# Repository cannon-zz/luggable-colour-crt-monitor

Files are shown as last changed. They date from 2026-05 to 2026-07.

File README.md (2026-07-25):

# Colour CRT Monitor for a Retro Luggable Computer

I'm in the process of assembling a luggable Apple ][ clone system.  This is the colour monitor part of the project.

This monitor started out as a SKYTEK brand SCT-1024 portable colour television from May of 1988 that I picked up from an auction site.  The video baseband and CRT driver section is built around a Panasonic 150CHB22 picture tube driven by a Toshiba TA7698AP video-chroma-deflection system all-in-one chip.  I think those picture tubes were quite common in small televisions of this type, and the all-in-one chip is easy to find, so this project might be useful for others looking for a way to make a small DIY CRT colour monitor from salvaged parts.

## Status

- [X] First pass through the circuit, entering it into kicad.
  - CRT socket board not included.  Will reuse as-is.
  - 11 V regulator circuit not included.  Considering alternatives.
- [X] Remove components from PCB, confirm values out-of-circuit.
  - Confirm internal structure of flyback.
  - Identify coils, diodes, capacitors.
- [X] Select new replacement parts.
- [X] Assign footprints.
- [X] Layout PCB.
- [X] Parts and PCBs ordered.
- [ ] Assembled.
- [ ] Tested and working (knock on wood).

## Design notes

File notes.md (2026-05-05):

# Notes

There are no documents for this specific make and model online that I can find.  The data sheet for the TA7698AP chip is available, which includes a reference circuit for an NTSC application.  That chip was used in at least one colour television service technician training kit, so there's a lot of helpful tutorial-like material floating around online about the operation and maintenance of circuits based on it.  Researching small portable televisions I learned that SKYTEK was probably one of a pantheon of small Korean and Taiwanese companies that licensed or copied older Japanese designs and sold them into the discount market, and based on that I looked for cosmetically similar Japanese televisions and found the JVC CX-60, which appears to be physically identical.  Service manuals for the PAL/SECAM European version of the CX-60 are available online, but not NTSC.  Other than the colour processing circuits, the schematic matches almost exactly what's inside this television, even the component designators are identical or closely related, and so should provide a useful guide for adjusting the circuit.

Using the PAL/SECAM CX-60ME service manual and the TA7698AP data sheet as guides, I traced out the schematic for my set.  The two major differences from the CX-60ME are:
* The absence of the PAL/SECAM colour processing circuitry ... replaced with a tint control.
* The SKYTEK has a different fly-back transformer, with fewer taps on the primary winding.  In particular, the CX-60 derives a +17 V DC supply for the vertical deflection circuit from one of its transformer's primary's taps, whereas the SKYTEK doesn't have that and uses its main regulated 11 V DC supply to power the vertical deflection.  The substantially lower voltage leads to significantly different component values in that part of the circuit.

## Power Supply

The TV's DC barrel jack is labelled "12 V".  It was powered by an external unregulated DC power supply labelled an oddly precise 14.7 V at 1.3 A.  The TV was also intended to be powered from an automotive cigarette lighter, so it was basically getting fed about 14 V, unregulated.  Internally, that feeds a linear 11.0 V DC regulator from which everything is powered.  That regulator is precise:  it has a temperature compensated zener reference and a voltage adjust pot.  So the circuit needs a clean, precise, regulated 11.0 V supply.  It would be very convenient if the circuit could run on a (clean, regulated) 12 V supply because that's one of the power supplies the computer already has.

Most of the circuit is actually powered by a 10-ish V rail which is derived from the 11 V rail using a simple series drop resistor.  Adjusting that resistor is probably all that's needed to accommodate a higher 12 V supply.  The real problem is the horizontal and vertical deflection circuits.  I don't know enough about these circuits to understand how the supply voltage affects the component values needed to get the amplitude and frequency of the oscillations in spec.  However, given the dramatic changes in resistor values for the transistor biasing in the vertical deflection circuit compared to the CX-60, where that circuit runs on 17 V, I think changing the supply voltage to these circuits needs to be done with care.  For now I'm expecting to have to include an 11.0 V regulator circuit.

Oddly, the TA7698AP data sheet recommends a supply voltage of 12 V, and says the minimum operating voltage is 10.8 V, which is *above* the voltage indicated on the VCC pin in the CX-60 schematic (10.6 V).

## Diodes

All diodes specified to be 1SS133 in the CX60 schematic are, here, parts marked "48T" around their barrel, or some cyclic permutation thereof (don't know where the start and end of the sequence are).  I believe they are 1N4148 equivalent.

D303 that does something I don't understand for the vertical deflection coil's high-side drive transistor is a 1SR35-100A in the CX60 schematic, and I don't know what's installed in the SKYTEK.  The 1SR35-100A datasheet is easy to find, but the part isn't.  I'll use a 1N4935.

D404 is a TVR06D, and D408 is an RGP10G.  These can also both be replaced with 1N4935.  I'll order extra 1N4935s, but to start I'll reuse the parts for these I have.

The diode (D405) used to rectify the 90 V supply for the CRT socket board has burned the PCB.  That's the only place on the PCB with evidence of heat, the only indication of a component that needed to handle more power than it was rated for.  I don't know what the diode is, I can't make heads or tails of the markings on it ("K4K4"), but I want to choose something else.  The diode seems healthy, so my plan is to re-use it, then with it in circuit measure the current and voltage it needs to handle, and replace it with something beefier that doesn't get as hot.  The CX60 used an ISR124-400A which is a 400 V 1 A high-speed rectifier diode.

In the CX60 schematic the horizontal pulse signal providing a phase sense feedback from the horizontal fly-back circuit feeds into four portions of the circuit:
1. a circuit to derive a horizontal blanking signal that gets mixed into the luminance;
2. the circuit tuning the horizontal oscillator;
3. the TA7698AP's h pulse in / gate pulse out pin;
4. the PAL/SECAM colour processor chip.

In the CX60, the 3 and 4 circuits share the same initial portions, including a zener diode (D303) to clamp the positive-going pulse amplitude.  A very similar but completely independent circuit is used for 1, which also includes a zener diode (D502) but where that diode creates a DC bias voltage and is not used to clamp the pulse amplitude.  The TV I've got has a nearly identical circuit for 2, and does not have the PAL/SECAM colour processor, and it combines 1 and 3 into a single circuit.  That circuit has basically the same parts as used in 3 above, but instead of a zener diode to clamp the positive-going voltage there is simply another "48T" diode (D402), identical to all the rest on the board.  This is more like the reference circuit in the data sheet, which shows a normal diode in this position.  I don't know what to make of this.  Did the person screw up and put the wrong component into this position, should it have been a zener diode?  Is the reference circuit in error?

I've decided to assume the reference circuit is correct, the diode does not need to clamp the positive-going voltage, and it can be the same as the other small signal diodes in the circuit.

## Inductors

All of the normal inductors I've managed to measure and document, but there are two that I don't know what to make of.

There is a tunable inductor thingy connected to the TA7698AP'S "burst cleaning" pin.  The package is marked KRFE204, and the circuit diagrams suggest it's a capacitor and variable inductor in parallel inside a single box.  The package I have has 5 pins, not including the tabs on the shield surrounding it, and only 2 of the 5 are used, the rest are all grounded.  I don't know what its parameters are or what it is exactly.  I'm reusing the one I pulled out of the TV, and will reconnect it the way it was hooked up.  Looking at the chip's block diagram, the various schematics, and considering what the pin description says about it, I /believe/ you're supposed to connect a DC-isolated LC band-reject filter to pin 10 that is tuned to the colour sub-carrier frequency (~3.58 MHz for NTSC) and that shunts everything away from its centre frequency to ground.  The pin description says the LC tank circuit's alignment can be used to shift the phase of the chroma signal w.r.t. the colour burst phase reference.  So ... I think you should look for a 3.58 MHz tunable LC circuit in a can which is to be deliberately mistuned slightly to provide a phase shift and tweak the colours.  I am expecting to adjust it by putting the tint control in the centre, and tweaking the inductor until the colours look right.  There are instructions in the CX60ME manual for adjusting this component (which it calls a transformer), but I don't yet know if they work for this circuit because of the differences in NTSC chroma processing.

There is also a transformer used to drive the horizontal output transistor.  Televisions seem to always include such a transformer, I don't really understand why, and so I don't know what this thing's properties are supposed to be.  I'm reusing the one I pulled out of the TV and connecting it up the way I found it.  Measuring this transformer:
 - grounded pins 2 and 4 (signal generator and oscilloscope chassis);
 - placed 15 kHz sine wave into pin 1, measured it to be 1 V peak-to-peak using 1 MOhm oscilloscope probe in parallel across winding;
 - simultaneously observed 250 mV peak-to-peak sine wave in phase on pin 3 with a second 1 MOhm oscilloscope probe across the winding;
 - with the ground lead for the probe on the secondary disconnected the amplitude increased to 1 V peak-to-peak.
 - the primary is measured to be 11 mH at 10 kHz with the secondary open, and 0.93 mH with the secondary shorted.

For the two ferrite beads, L401 and L409, using a dual binding post to BNC adapter + BNC to SMA adapter, I used a NanoVNA to try to characterize these.  If the measurements I made are correct, below 30 MHz these have almost 0 Ohm impedance, above 30 MHz they begin to absorb, and have a peak absoption at about 160 MHz.

## Resistors

All blue resistors had drifted upwards, all were consistently measured 10% above their marked value.

### Variable resistors

All variable resistors measured consistently 20% below their marked value.  The fact that the deviation is systematic points to a manufacturing flaw, but normal non-precision variable resistors usually only have a 20% or even 30% tolerance, so these would probably all be within the manufacturer's specifications.  Nevertheless I'll replace them all.

Some are hard to source:
- 470 Ohm vertical centre.  with no load on wiper, wiper potential varies from 3.5 V to 9.1 V, or 32% to 83% of the deflection potential.  in the CX60 circuit, with different resistances and the vertical deflection running on 17 V, the unloaded wiper's potential varies from 6.3 V to 12.6 V, or 37% to 74% of the deflection potential.
- 200 kOhm vertical hold

Easy to obtain locally are Alps Alpine RK09K series potentiometers.  for the three 10 kOhm, non-detent, pots I got RK09L1140-F15-C0-B103:
- 15 mm from body to top of shaft
- 5 mm M9x0.75 threaded sleeve
- 6 mm flat D shaft
- 300 degree rotation
- pins comatible with 2.54 mm grid
- 10 mm from PCB to front-panel mating surface
- 50 mW
Mouser has the centre detent version RK09L114001E

TT Electronics P0915N-FCxxx are nearly mechanically compatible, but have an M7x0.75 threaded shaft.  there isn't a 200 kOhm variant.

settled on Bourns PDB12-F4201-204BF for the 200 kOhm vertical hold adjustment.  this is larger, physically, than the others, does not have a threaded bushing, but its PCB to front-panel mating surface height is nearly the same at 9 mm, however the total length is about 5 mm shorter from PCB surface to end of shaft.  hopefully the difference won't be noticed once knobs get pushed onto the shafts.

it would be much more convenient if the vertical hold adjustment R351 could be implemented with a 100 kOhm pot.  upping R306 to 270 kOhm and adding a 50 kOhm resistor in series after R351 would allow R351 to be reduced to 100 kOhm without changing the total series resistance, but it would cut the adjustment range in half.

## Transistors

### 2SC200

Can't find a manufacturer's datasheet for the 2SC200 transistor, Q401, the NPN used to drive the horizontal output transformer.  Web sites that claim to have data for this part contradict each other.  What I have found:
 - A contemporary transistor parameter table lists it as a Fujitsu part having RF conversion mixer, oscillator and power amplifier applications, states the collector-base breakdown voltage is 40 V, the max collector current is 300 mA, the max dissipated power is 600 mW, max junction temperature is 175 C, the transition frequency is 350 MHz, and the current gain is 60.
 - A contemporary cross-reference table says the 2SC200 can be replaced with:  2SC1175, 2SC594, 2SC138, 2SC139, 2SC696, 2SC741
 - The CX60 uses a 2SD639-Q or -R for its Q501, the equivalent in its circuit.  Those have:  collector-base breakdown voltage of 60 V, collector-emitter breakdown voltage of 50 V, max collector current 500 mA, max dissipated power 600 mW, max temperature 150 C, transition frequency of 200 MHz, and a current gain between 85 and 240.
 - One non-contemporary web site claims the transistor has a collector emitter breakdown voltage of 45 V, a max collector current of 0.5 A, dissipates a maximum of 0.625 W, has a transition frequency of 300 MHz, and that the Y rating will have a current gain between 120 and 240.
 - That site claims it can be replaced with:  2SC2274, 2SC2274K, 2SC2277, 2SC2655, 2SC3243, 2SC3328, 2SC3916, 2SC3917, 2SC3918, 2SC3919, 2SC3920, 2SC3921, 2SC3922, 2SC3923, 2SD438, 2SD667, 2SD863, BC635, KSC1008C, KSC2331, KTC200, KTC3209 or KTD863.
 - Another non-contemporary web site claims it has a collector base breakdown voltage of 40 V, a max collector current of 0.3 A, dissipates a maximum of 0.65 W, has a transition frequency of 175 MHz, and a current gain of 60 (regardless of rating).
 - 2N5551, 2SCR514R might be suitable modern replacements, or maybe just a 2N2222

## Delay Line

I have no idea what this is.  "Sangshin DL601T" is written on it, but I can't find any information on that.  The CX60 schematic isn't helpful because that's for a PAL/SECAM television which would need a different component here.  The TDA7698AP reference circuit shows a TRF2033 or TRP2033 (bad scan) used in this part of the circuit, and I can't find any information about that on the internet.  The schematic calls it a 3.58 MHz trap, and the block diagram suggests it is an LC band reject filter combined with a delay line.

I tried injecting a 100 mV sine wave into pin 1, grounding pin 2, looking at the output on pin 3, and sweeping the frequency between 1 MHz and 5 MHz.  It definitely seems to be a filter, but my quickie hack wasn't enough to get a sense of what kind it is.  However, if it's also a delay line that's hard to tell.  At low frequencies, below 100 kHz, there's no obvious phase difference, no time delay between the input and output signals.  Increasing the frequency reveals a frequency dependent phase shift but not one that corresponds to a fixed time delay.  Injecting, instead, a square wave produces long ringing tails on each transition.  In the circuit, it has a 10 V DC bias across it, between both its input and output and the ground pin.  I wonder if that's needed to make it work.  There might be active circuitry inside it.

## Connectors

The 4 pin and 5 pin connectors for the CRT socket board are, I think, KK series connectors.  kicad doesn't have footprints for them, so I just picked some 2.5 mm pitch footprints that looked to have about the right size outline.

## Capacitors

The 1 uF 50 V capacitors C205, C401, C408, C409, C503 can all be rated for much less than 50 V.  I found 25 V MLCC capacitors in 2012mm packages to use instead of electrolytics.

C208 the 10 uF 50 V filter capacitor for brightness can be reduced to 16 V rating and replaced with an MLCC in a 2012 package.

For the rest, some were cheaper to buy in 1608 (metric) sizes than the 2012 size that I had thought I'd standardize on.  I decided not to change the footprints for those parts because 1608s can be soldered onto 2012 pads and this way there's maybe more flexibility for changing values if needed.

## Other Similar Televisions

The Panasonic TH6-X3V uses the same picture tube, but a different all-in-one chip.  Other TVs that I believe are similar, that I found in my search for a schematic, include:
* Jericho color TV J-210
* Jaxon CT-105
* Hitachi C6-GL3
* National TH6-X300
* National TH6-X7

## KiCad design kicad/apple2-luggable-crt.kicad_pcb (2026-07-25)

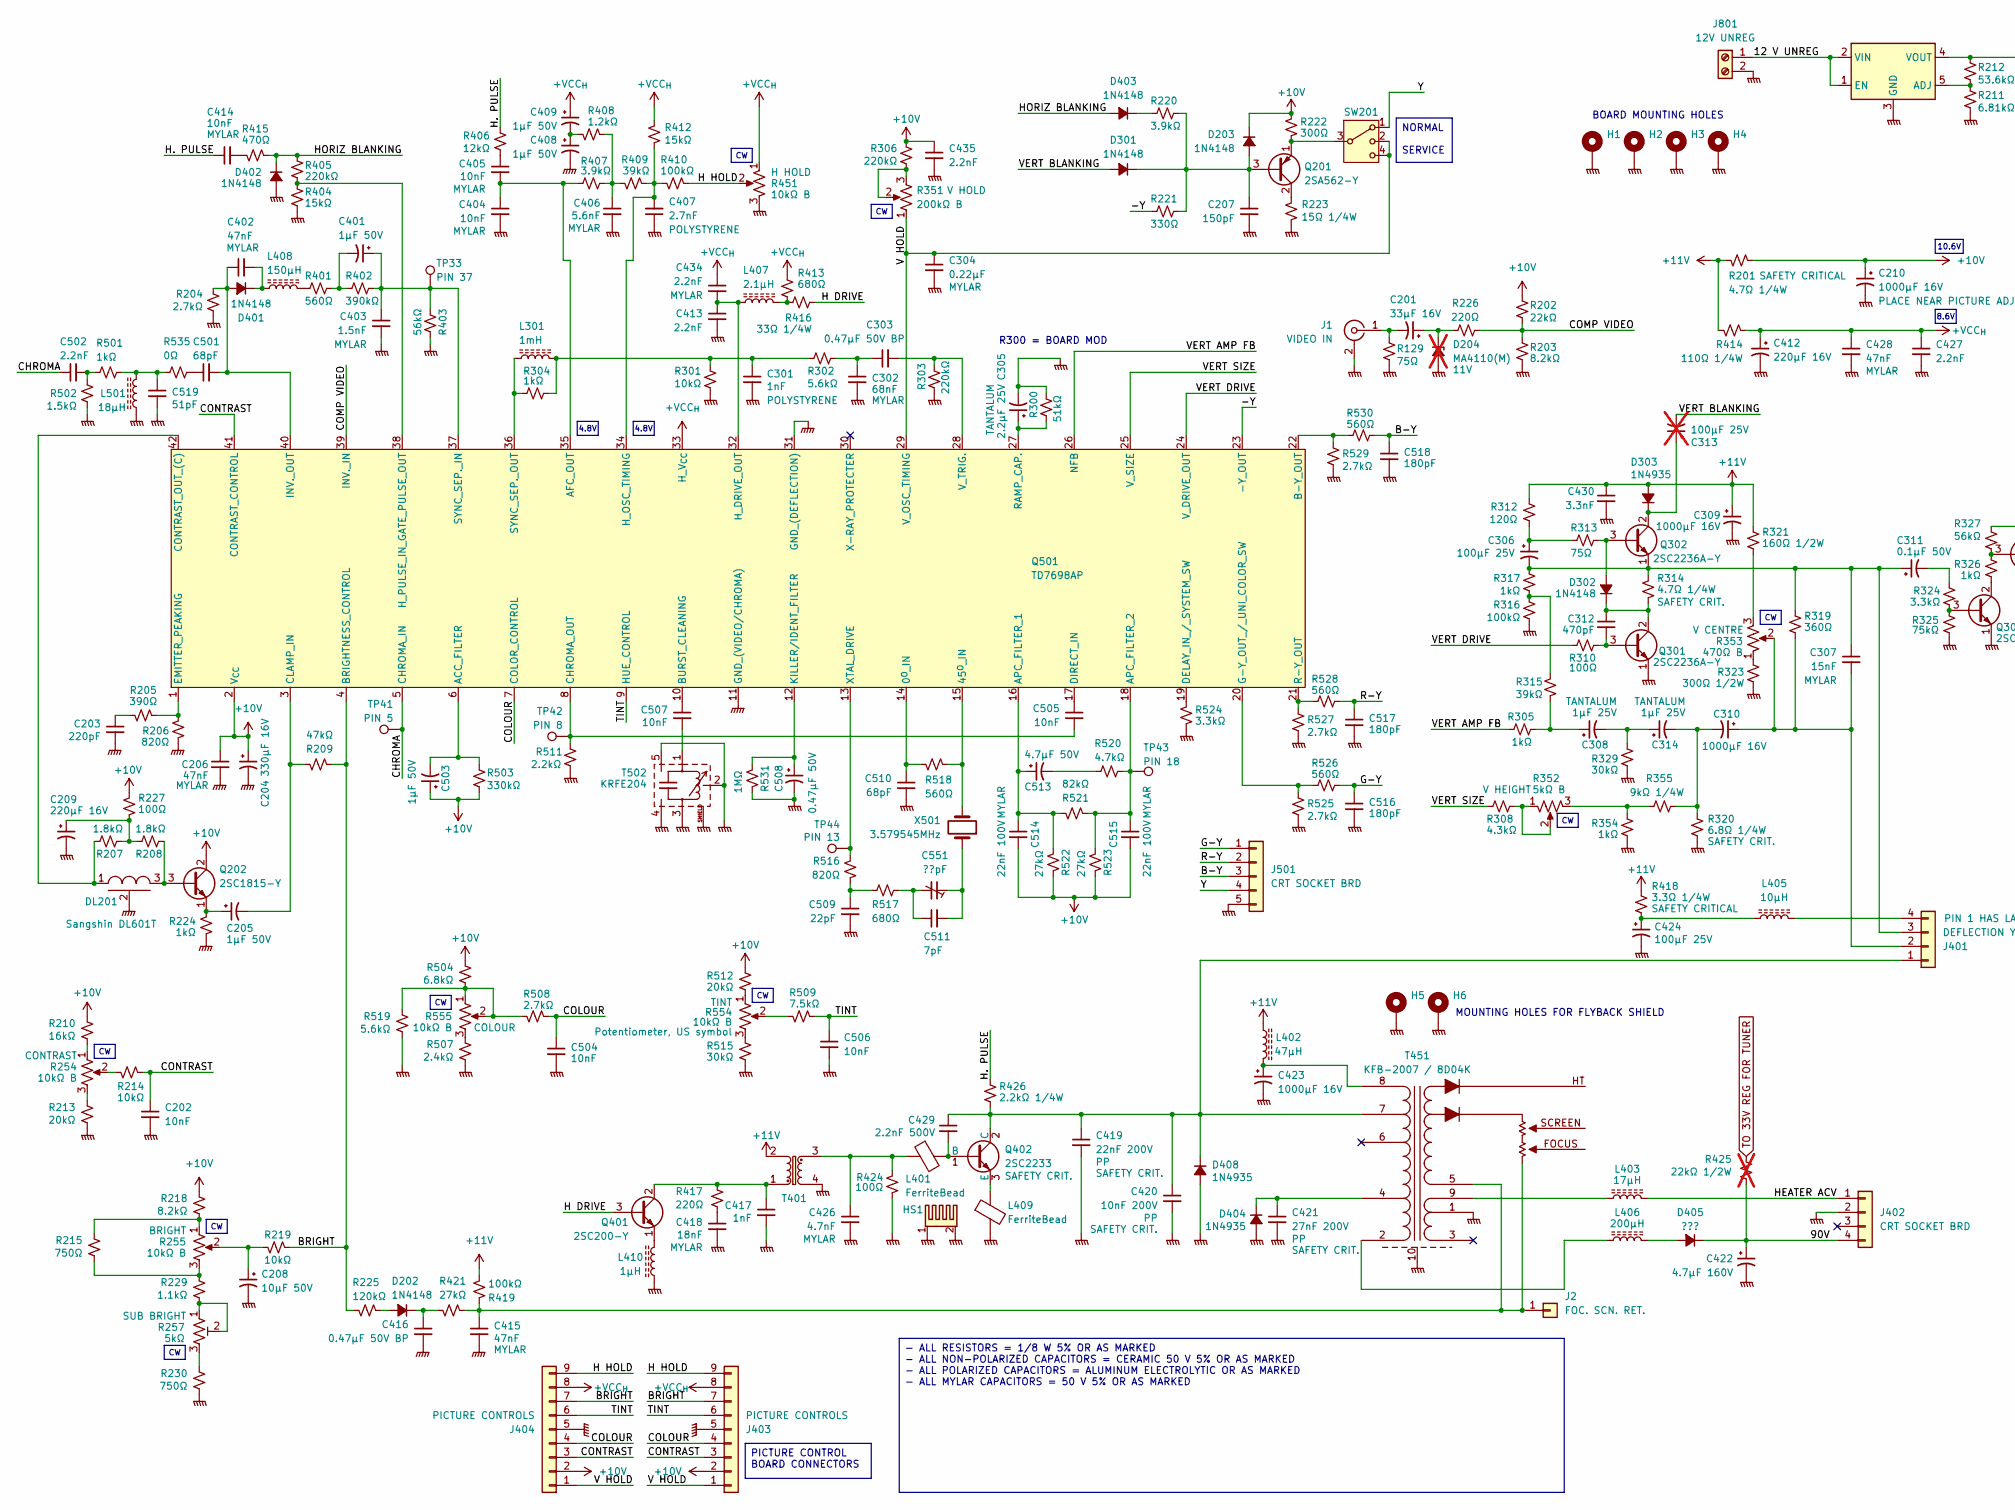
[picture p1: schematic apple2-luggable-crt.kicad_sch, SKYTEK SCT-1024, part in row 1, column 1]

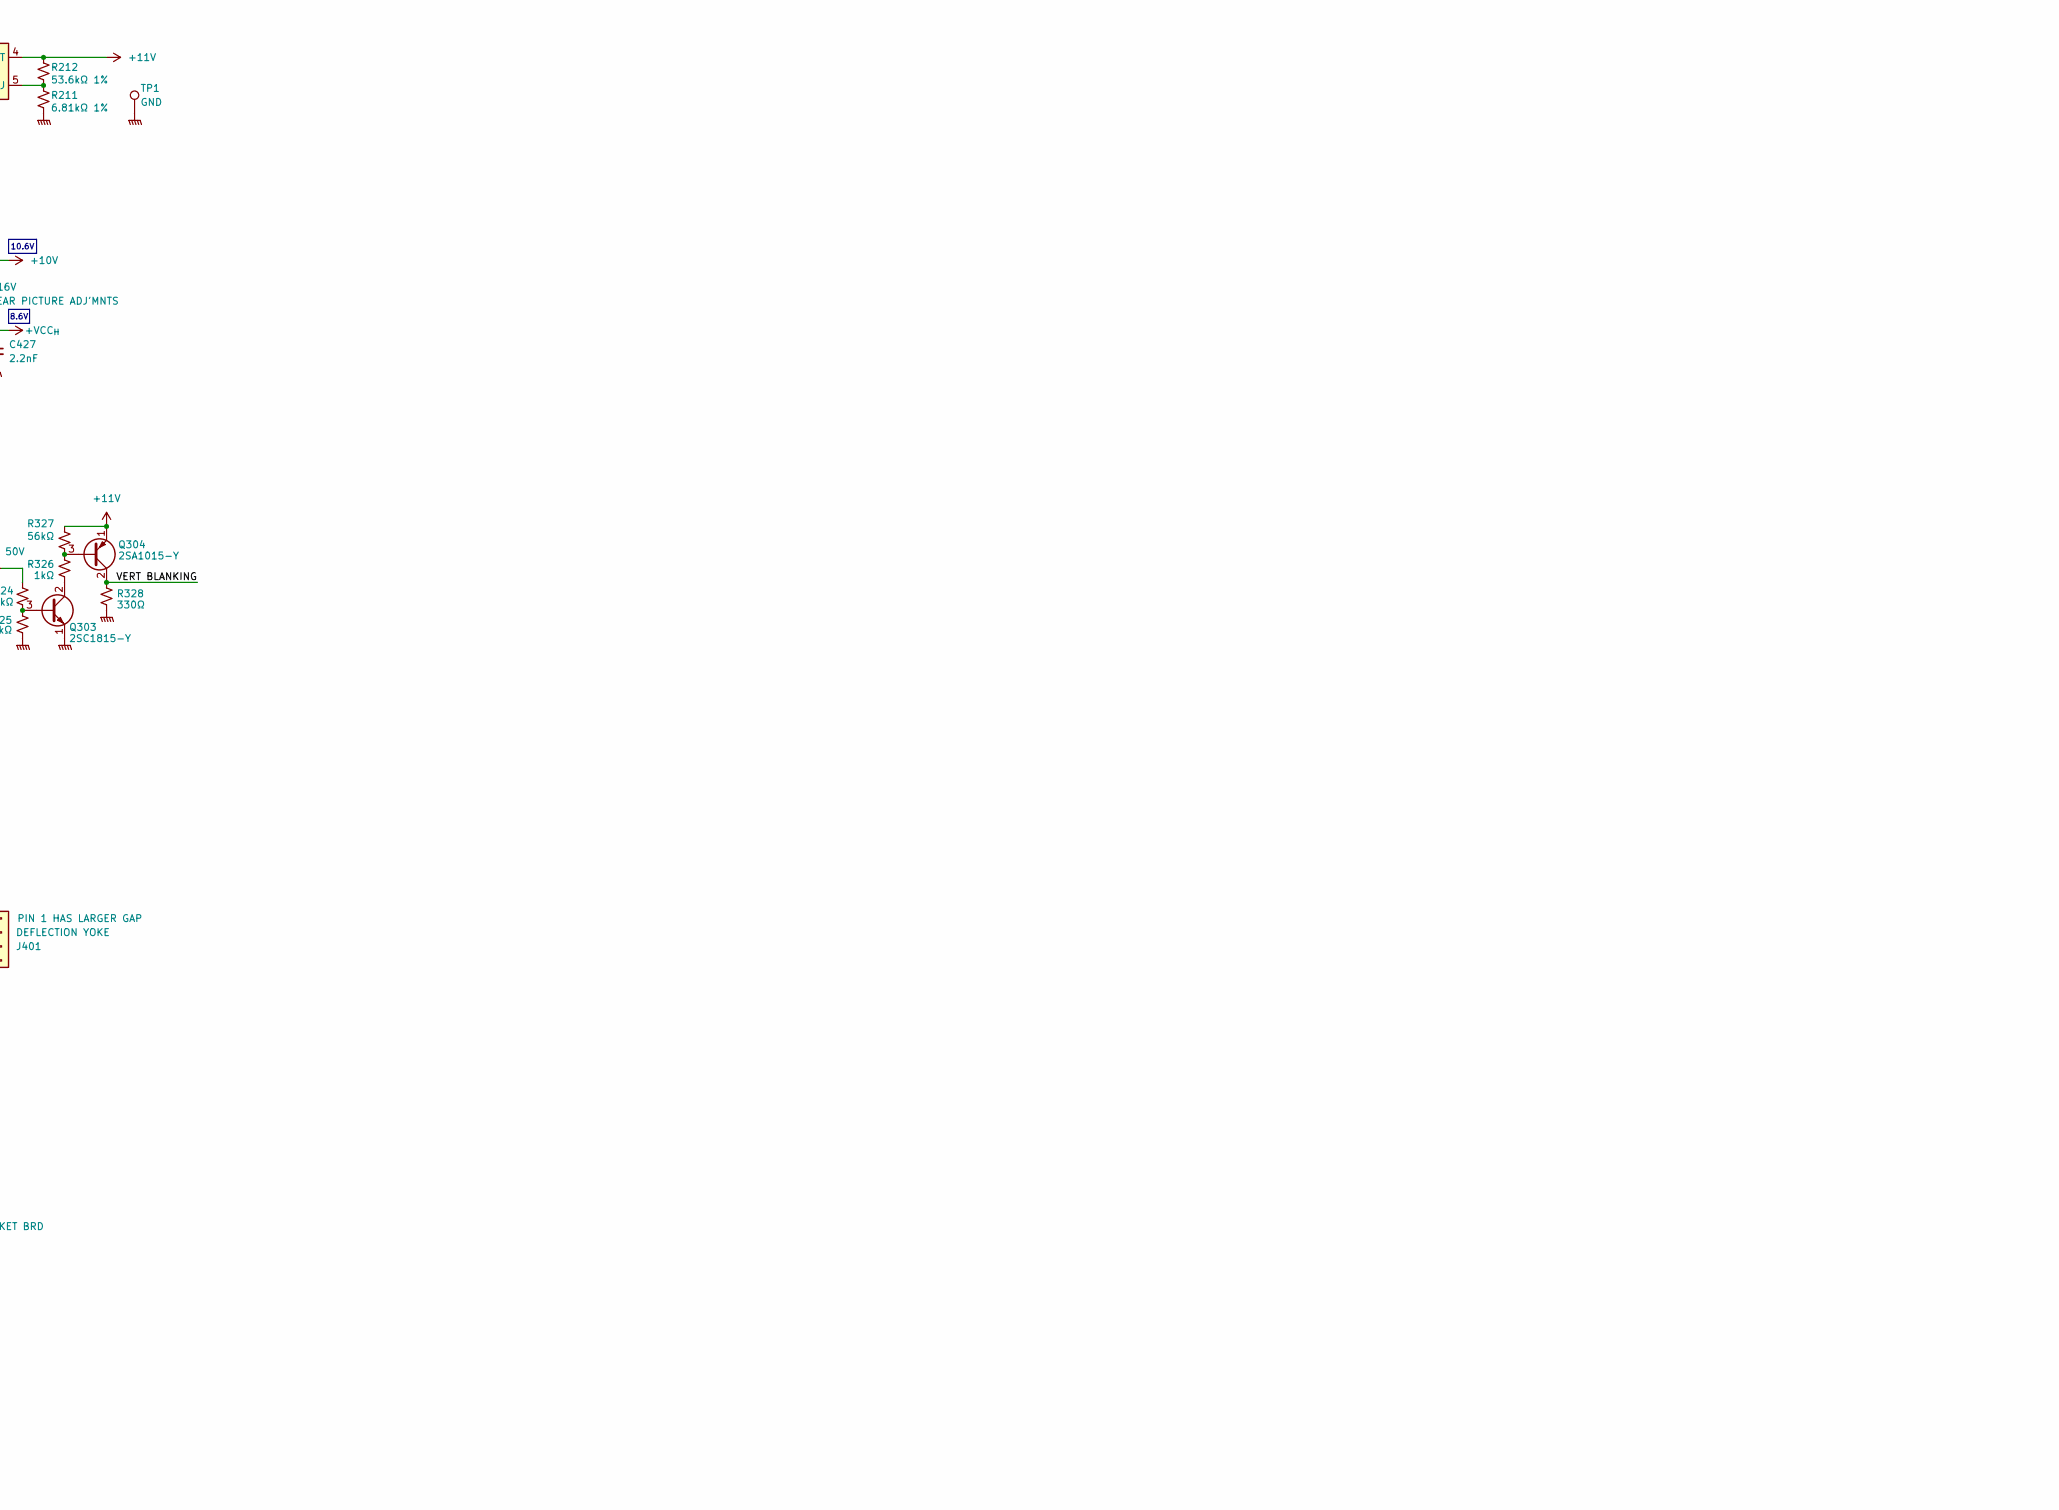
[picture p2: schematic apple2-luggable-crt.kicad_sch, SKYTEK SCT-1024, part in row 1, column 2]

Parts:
C201: 33μF 16V; CP_Radial_D5.0mm_P2.00mm
C202, C404, C405, C414, C504, C505, C506, C507: 10nF; C_0805_2012Metric_Pad1.18x1.45mm_HandSolder
C203: 220pF; C_0805_2012Metric_Pad1.18x1.45mm_HandSolder
C204: 330μF 16V; CP_Radial_D8.0mm_P3.50mm
C205, C401, C408, C409, C503: 1μF 50V; C_0805_2012Metric_Pad1.18x1.45mm_HandSolder
C206, C402, C415, C428: 47nF; C_0805_2012Metric_Pad1.18x1.45mm_HandSolder
C207: 150pF; C_0805_2012Metric_Pad1.18x1.45mm_HandSolder
C208: 10μF 50V; C_0805_2012Metric_Pad1.18x1.45mm_HandSolder
C209, C412: 220μF 16V; CP_Radial_D8.0mm_P3.50mm
C210, C309, C310, C423: 1000μF 16V; CP_Radial_D8.0mm_P3.50mm
C301, C417: 1nF; C_0805_2012Metric_Pad1.18x1.45mm_HandSolder
C302: 68nF; C_0805_2012Metric_Pad1.18x1.45mm_HandSolder
C303, C416: 0.47μF 50V BP; C_0805_2012Metric_Pad1.18x1.45mm_HandSolder
C304: 0.22μF; C_0805_2012Metric_Pad1.18x1.45mm_HandSolder
C305: 2.2μF 25V; C_0805_2012Metric_Pad1.18x1.45mm_HandSolder
C306, C424: 100μF 25V; CP_Radial_D6.3mm_P2.50mm
C307: 15nF; C_0805_2012Metric_Pad1.18x1.45mm_HandSolder
C308, C314: 1μF 25V; C_0805_2012Metric_Pad1.18x1.45mm_HandSolder
C311: 0.1μF 50V; C_0805_2012Metric_Pad1.18x1.45mm_HandSolder
C312: 470pF; C_0805_2012Metric_Pad1.18x1.45mm_HandSolder
C313: 100μF 25V; CP_Radial_D8.0mm_P3.50mm; not fitted
C403: 1.5nF; C_0805_2012Metric_Pad1.18x1.45mm_HandSolder
C406: 5.6nF; C_0805_2012Metric_Pad1.18x1.45mm_HandSolder
C407: 2.7nF; C_0805_2012Metric_Pad1.18x1.45mm_HandSolder
C413, C427, C434, C435, C502: 2.2nF; C_0805_2012Metric_Pad1.18x1.45mm_HandSolder
C418: 18nF; C_0805_2012Metric_Pad1.18x1.45mm_HandSolder
C419: 22nF 200V; C_Rect_L10.3mm_W4.5mm_P7.50mm_MKS4
C420: 10nF 200V; C_Rect_L10.3mm_W4.5mm_P7.50mm_MKS4
C421: 27nF 200V; C_Rect_L10.3mm_W4.5mm_P7.50mm_MKS4
C422: 4.7μF 160V; CP_Radial_D6.3mm_P2.50mm
C426: 4.7nF; C_0805_2012Metric_Pad1.18x1.45mm_HandSolder
C429: 2.2nF 500V; C_0805_2012Metric_Pad1.18x1.45mm_HandSolder
C430: 3.3nF; C_0805_2012Metric_Pad1.18x1.45mm_HandSolder
C501, C510: 68pF; C_0805_2012Metric_Pad1.18x1.45mm_HandSolder
C508: 0.47μF 50V; C_0805_2012Metric_Pad1.18x1.45mm_HandSolder
C509: 22pF; C_0805_2012Metric_Pad1.18x1.45mm_HandSolder
C511: 7pF; C_0805_2012Metric_Pad1.18x1.45mm_HandSolder
C513: 4.7μF 50V; C_0805_2012Metric_Pad1.18x1.45mm_HandSolder
C514, C515: 22nF 100V; C_0805_2012Metric_Pad1.18x1.45mm_HandSolder
C516, C517, C518: 180pF; C_0805_2012Metric_Pad1.18x1.45mm_HandSolder
C519: 51pF; C_0805_2012Metric_Pad1.18x1.45mm_HandSolder
C551: ??pF; C_Rect_L7.0mm_W6.5mm_P5.00mm
D202, D203, D301, D302, D401, D402, D403: 1N4148; D_MiniMELF_Handsoldering
D204: MA4110(M); not fitted
D303, D404, D408: 1N4935; D_DO-41_SOD81_P10.16mm_Horizontal
D405: ???; D_DO-41_SOD81_P10.16mm_Horizontal
DL201: Sangshin DL601T; DelayLine_Sangshin_DL601T
H1, H2, H3, H4: M4; MountingHole_4.3mm_M4_Pad_TopBottom
H5, H6: M3; MountingHole_3.2mm_M3_Pad_TopBottom_flyback_shield
HS1: Heatsink_Pad_2Pin; Heatsink_TO-220_26x20mm_2xFixation1.2mm
J1: VIDEO IN; BNC_TEConnectivity_1478204_Vertical
J2: FOC. SCN. RET.; PinHeader_1x01_P2.54mm_Vertical
J401: DEFLECTION YOKE; DEFLECTION_CONNECTOR
J402: CRT SOCKET BRD; JST_XH_B4B-XH-A_1x04_P2.50mm_Vertical
J403, J404: PICTURE CONTROLS; JST_PH_B9B-PH-K_1x09_P2.00mm_Vertical
J501: CRT SOCKET BRD; JST_XH_B5B-XH-A_1x05_P2.50mm_Vertical
J801: 12V UNREG; JST_VH_B2P-VH_1x02_P3.96mm_Vertical
L301: 1mH; L_1008_2520Metric_Pad1.43x2.20mm_HandSolder
L401, L409: FerriteBead; Ferrite_L12.0mm_D3.2mm_P18.0mm_Horizontal
L402: 47μH; L_Radial_D7.8mm_P5.00mm_Fastron_07HCP
L403: 17μH; L_Radial_D6.0mm_P8.00mm
L405: 10μH; L_Radial_D10.0mm_P7.62mm
L406: 200μH; L_Radial_D7.5mm_P5.00mm_Fastron_07P
L407: 2.1μH; L_Radial_D7.5mm_P5.00mm_Fastron_07P
L408: 150μH; L_TDK_NLV32_3.2x2.5mm
L410: 1μH; L_Radial_D7.5mm_P5.00mm_Fastron_07P
L501: 18μH; L_TDK_NLV32_3.2x2.5mm
Q201: 2SA562-Y; TO-92_Inline_Wide
Q202, Q303: 2SC1815-Y; TO-92_Inline_Wide
Q301, Q302: 2SC2236A-Y; TO-92_Inline_Wide
Q304: 2SA1015-Y; TO-92_Inline_Wide
Q401: 2SC200-Y; TO-92_Inline_Wide
Q402: 2SC2233; TO-220-3_Vertical
Q501: TD7698AP; DIP-42_W15.24mm_LongPads
R129, R313: 75Ω; R_1206_3216Metric_Pad1.30x1.75mm_HandSolder
R201, R314: 4.7Ω 1/4W; R_Axial_DIN0207_L6.3mm_D2.5mm_P15.24mm_Horizontal
R202: 22kΩ; R_1206_3216Metric_Pad1.30x1.75mm_HandSolder
R203, R218: 8.2kΩ; R_1206_3216Metric_Pad1.30x1.75mm_HandSolder
R204, R508, R525, R527, R529: 2.7kΩ; R_1206_3216Metric_Pad1.30x1.75mm_HandSolder
R205: 390Ω; R_1206_3216Metric_Pad1.30x1.75mm_HandSolder
R206, R516: 820Ω; R_1206_3216Metric_Pad1.30x1.75mm_HandSolder
R207, R208: 1.8kΩ; R_1206_3216Metric_Pad1.30x1.75mm_HandSolder
R209: 47kΩ; R_1206_3216Metric_Pad1.30x1.75mm_HandSolder
R210: 16kΩ; R_1206_3216Metric_Pad1.30x1.75mm_HandSolder
R211: 6.81kΩ 1%; R_1206_3216Metric_Pad1.30x1.75mm_HandSolder
R212: 53.6kΩ 1%; R_1206_3216Metric_Pad1.30x1.75mm_HandSolder
R213, R512: 20kΩ; R_1206_3216Metric_Pad1.30x1.75mm_HandSolder
R214, R219, R301: 10kΩ; R_1206_3216Metric_Pad1.30x1.75mm_HandSolder
R215, R230: 750Ω; R_1206_3216Metric_Pad1.30x1.75mm_HandSolder
R220, R407: 3.9kΩ; R_1206_3216Metric_Pad1.30x1.75mm_HandSolder
R221, R328: 330Ω; R_1206_3216Metric_Pad1.30x1.75mm_HandSolder
R222: 300Ω; R_1206_3216Metric_Pad1.30x1.75mm_HandSolder
R223: 15Ω 1/4W; R_1206_3216Metric_Pad1.30x1.75mm_HandSolder
R224, R304, R305, R317, R326, R354, R501: 1kΩ; R_1206_3216Metric_Pad1.30x1.75mm_HandSolder
R225: 120kΩ; R_1206_3216Metric_Pad1.30x1.75mm_HandSolder
R226, R417: 220Ω; R_1206_3216Metric_Pad1.30x1.75mm_HandSolder
R227, R310, R424: 100Ω; R_1206_3216Metric_Pad1.30x1.75mm_HandSolder
R229: 1.1kΩ; R_1206_3216Metric_Pad1.30x1.75mm_HandSolder
R254, R255, R451, R554, R555: 10kΩ B; Potentiometer_Alpha_RD901F-40-00D_Single_Vertical_CircularH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
R257: 5kΩ; Potentiometer_Bourns_3386F_Vertical
R300: 51kΩ; R_1206_3216Metric_Pad1.30x1.75mm_HandSolder
R302, R519: 5.6kΩ; R_1206_3216Metric_Pad1.30x1.75mm_HandSolder
R303, R306, R405: 220kΩ; R_1206_3216Metric_Pad1.30x1.75mm_HandSolder
R308: 4.3kΩ; R_1206_3216Metric_Pad1.30x1.75mm_HandSolder
R312: 120Ω; R_1206_3216Metric_Pad1.30x1.75mm_HandSolder
R315, R409: 39kΩ; R_1206_3216Metric_Pad1.30x1.75mm_HandSolder
R316, R410, R419: 100kΩ; R_1206_3216Metric_Pad1.30x1.75mm_HandSolder
R319: 360Ω; R_1206_3216Metric_Pad1.30x1.75mm_HandSolder
R320: 6.8Ω 1/4W; R_Axial_DIN0207_L6.3mm_D2.5mm_P15.24mm_Horizontal
R321: 160Ω 1/2W; R_1206_3216Metric_Pad1.30x1.75mm_HandSolder
R323: 300Ω 1/2W; R_1206_3216Metric_Pad1.30x1.75mm_HandSolder
R324, R524: 3.3kΩ; R_1206_3216Metric_Pad1.30x1.75mm_HandSolder
R325: 75kΩ; R_1206_3216Metric_Pad1.30x1.75mm_HandSolder
R327, R403: 56kΩ; R_1206_3216Metric_Pad1.30x1.75mm_HandSolder
R329, R515: 30kΩ; R_1206_3216Metric_Pad1.30x1.75mm_HandSolder
R351: 200kΩ B; Potentiometer_Alpha_RD901F-40-00D_Single_Vertical_CircularH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
R352: 5kΩ B; Potentiometer_Bourns_3386F_Vertical
R353: 470Ω B; Potentiometer_Bourns_3386F_Vertical
R355: 9kΩ 1/4W; R_1206_3216Metric_Pad1.30x1.75mm_HandSolder
R401, R518, R526, R528, R530: 560Ω; R_1206_3216Metric_Pad1.30x1.75mm_HandSolder
R402: 390kΩ; R_1206_3216Metric_Pad1.30x1.75mm_HandSolder
R404, R412: 15kΩ; R_1206_3216Metric_Pad1.30x1.75mm_HandSolder
R406: 12kΩ; R_1206_3216Metric_Pad1.30x1.75mm_HandSolder
R408: 1.2kΩ; R_1206_3216Metric_Pad1.30x1.75mm_HandSolder
R413, R517: 680Ω; R_1206_3216Metric_Pad1.30x1.75mm_HandSolder
R414: 110Ω 1/4W; R_1206_3216Metric_Pad1.30x1.75mm_HandSolder
R415: 470Ω; R_1206_3216Metric_Pad1.30x1.75mm_HandSolder
R416: 33Ω 1/4W; R_1206_3216Metric_Pad1.30x1.75mm_HandSolder
R418: 3.3Ω 1/4W; R_Axial_DIN0207_L6.3mm_D2.5mm_P15.24mm_Horizontal
R421, R522, R523: 27kΩ; R_1206_3216Metric_Pad1.30x1.75mm_HandSolder
R425: 22kΩ 1/2W; not fitted
R426: 2.2kΩ 1/4W; R_1206_3216Metric_Pad1.30x1.75mm_HandSolder
R502: 1.5kΩ; R_1206_3216Metric_Pad1.30x1.75mm_HandSolder
R503: 330kΩ; R_1206_3216Metric_Pad1.30x1.75mm_HandSolder
R504: 6.8kΩ; R_1206_3216Metric_Pad1.30x1.75mm_HandSolder
R507: 2.4kΩ; R_1206_3216Metric_Pad1.30x1.75mm_HandSolder
R509: 7.5kΩ; R_1206_3216Metric_Pad1.30x1.75mm_HandSolder
R511: 2.2kΩ; R_1206_3216Metric_Pad1.30x1.75mm_HandSolder
R520: 4.7kΩ; R_1206_3216Metric_Pad1.30x1.75mm_HandSolder
R521: 82kΩ; R_1206_3216Metric_Pad1.30x1.75mm_HandSolder
R531: 1MΩ; R_1206_3216Metric_Pad1.30x1.75mm_HandSolder
R535: 0Ω; R_1206_3216Metric_Pad1.30x1.75mm_HandSolder
SW201: SW_SP3T; SW_SERVICE
T401: L_Ferrite_Coupled_1243; Transformer_Horiz_Drive
T451: KFB-2007 / 8D04K; Flyback
T502: KRFE204; CHROMA_FILTER
TP1: GND; TestPoint_THTPad_D3.0mm_Drill1.5mm
TP33: PIN 37; TestPoint_THTPad_D3.0mm_Drill1.5mm
TP41: PIN 5; TestPoint_THTPad_D3.0mm_Drill1.5mm
TP42: PIN 8; TestPoint_THTPad_D3.0mm_Drill1.5mm
TP43: PIN 18; TestPoint_THTPad_D3.0mm_Drill1.5mm
TP44: PIN 13; TestPoint_THTPad_D3.0mm_Drill1.5mm
U1: XRP29302ETBTR-L; TO-263-5_TabPin3
X501: 3.579545MHz; Crystal_HC49-U_Vertical

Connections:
+10V: C204.1, C206.1, C210.1, C435.1, C503.1, C514.2, C515.2, D203.1 (K), J403.2, J404.2, Q202.2 (C), Q501.2 (V_{CC}), R201.2, R202.1, R210.1, R218.1, R222.2, R227.2, R306.2, R503.2, R504.1, R512.1, R522.2, R523.2
+11V: C309.1, C430.1, D303.2 (A), L402.1, Q304.1 (E), R201.1, R212.1, R312.1, R321.1, R327.1, R414.2, R418.2, R419.2, T401.2, U1.4 (VOUT)
+VCC_{H}: C409.1, C412.1, C427.1, C428.1, C434.1, J403.8, J404.8, Q501.33 (H_V_{CC}), R412.1, R413.2, R414.1, R451.1
/12 V UNREG: J801.1, U1.1 (EN), U1.2 (VIN)
/90V: C422.1, D405.1 (K), J402.4, R425.1
/-Y: Q501.23 (-Y_OUT), R221.1
/B-Y: C518.1, J501.3, R530.2
/BRIGHT: J403.7, J404.7, Q501.4 (BRIGHTNESS_CONTROL), R209.2, R219.1, R225.2
/CHROMA: C502.1, Q501.5 (CHROMA_IN), TP41.1 (1_1)
/COLOUR: C504.1, J403.4, J404.4, Q501.7 (COLOR_CONTROL), R508.1
/COMP VIDEO: Q501.39 (INV._IN), R202.2, R203.1, R226.1
/CONTRAST: C202.1, J403.3, J404.3, Q501.41 (CONTRAST_CONTROL), R214.1
/G-Y: C516.1, J501.1, R526.2
/H DRIVE: Q401.3 (B), R416.2
/H HOLD: J403.9, J404.9, R410.1, R451.2
/H. PULSE: C414.1, R406.2, R426.2
/HEATER ACV: J402.1, L403.2
/HORIZ BLANKING: D402.1 (K), D403.2 (A), R405.2, R415.1
/R-Y: C517.1, J501.2, R528.2
/TINT: C506.1, J403.6, J404.6, Q501.9 (HUE_CONTROL), R509.1
/V HOLD: C304.1, J403.1, J404.1, Q501.29 (V_OSC_TIMING), R351.1, SW201.2, SW201.4
/VERT AMP FB: Q501.26 (NFB), R305.1
/VERT BLANKING: C313.2, D301.2 (A), Q304.2 (C), R328.1
/VERT DRIVE: Q501.24 (V_DRIVE_OUT), R310.1
/VERT SIZE: Q501.25 (V_SIZE), R308.1
/Y: J501.4, SW201.1
GNDPWR: C202.2, C203.2, C204.2, C206.2, C207.2, C208.2, C209.2, C210.2, C301.2, C302.2, C304.2, C305.2, C309.2, C403.2, C404.2, C406.2, C407.1, C408.2, C412.2, C413.2, C415.2, C416.2, C417.2, C418.2, C419.2, C420.2, C421.2, C422.2, C423.2, C424.2, C426.2, C427.2, C428.2, C430.2, C435.2, C504.2, C506.2, C508.2, C509.2, C510.2, C516.2, C517.2, C518.2, C519.2, D204.2 (A), D402.2 (A), D404.2 (A), D408.2 (A), DL201.2 (COMMUN), H1.1 (1_1), H2.1 (1_1), H3.1 (1_1), H4.1 (1_1), H5.1 (1_1), H6.1 (1_1), HS1.1, HS1.2, J1.2 (Ext), J402.2, J403.5, J404.5, J501.5, J801.2, L409.2, L410.2, L501.1, Q301.1 (E), Q303.1 (E), Q501.11 (GND_(VIDEO/CHROMA)), Q501.31 (GND_(DEFLECTION)), R129.2, R203.2, R204.2, R206.2, R211.2, R213.2, R223.1, R224.2, R230.2, R300.2, R301.1, R303.1, R316.2, R320.2, R323.2, R325.2, R328.2, R329.2, R354.2, R403.2, R404.2, R424.1, R451.3, R502.2, R507.2, R511.2, R515.2, R519.2, R524.2, R525.2, R527.2, R529.2, R531.2, T401.4, T451.1 (HEATER), T451.10, T502.2, T502.3, T502.4, T502.5, T502.SHIELD, TP1.1 (1_1), U1.3 (GND)
unnamed: C201.1, D204.1 (K), R226.2
unnamed: C203.1, R205.2
unnamed: C208.1, R219.2, R255.2
unnamed: C209.1, R207.1, R208.2, R227.1
unnamed: C301.1, L301.1, R301.2, R302.1, R304.1
unnamed: C302.1, C303.1, R302.2
unnamed: C306.1, R312.2, R313.1
unnamed: C308.1, R305.2, R315.2
unnamed: C308.2, C314.1, R329.1
unnamed: C310.2, C314.2, R320.1, R355.2
unnamed: C311.2, R324.2
unnamed: C401.2, R401.2, R402.1
unnamed: C405.1, R406.1
unnamed: C406.1, R407.2, R408.1, R409.2
unnamed: C408.1, C409.2, R408.2
unnamed: C414.2, R415.2
unnamed: C418.1, R417.1
unnamed: C423.1, L402.2, T451.8
unnamed: C424.1, L405.1, R418.1
unnamed: C426.1, L401.1, R424.2, T401.3
unnamed: C501.1, R535.1
unnamed: C502.2, R501.2, R502.1
unnamed: C507.2, T502.1
unnamed: C509.1, R516.2, R517.1
unnamed: C511.1, C551.2, R517.2
unnamed: C511.2, C551.1, X501.1
unnamed: C513.2, R520.1
unnamed: C519.1, L501.2, R501.1, R535.2
unnamed: D202.2 (A), R225.1
unnamed: C416.1, D202.1 (K), R421.1
unnamed: C207.1, D203.2 (A), D301.1 (K), Q201.3 (B), R220.2, R221.2
unnamed: D302.2 (A), Q302.3 (B), R313.2
unnamed: C312.1, D302.1 (K), Q301.2 (C), R314.2
unnamed: C313.1, D303.1 (K), Q302.2 (C)
unnamed: C402.1, C501.2, D401.2 (A), Q501.40 (INV._OUT), R204.1
unnamed: C402.2, D401.1 (K), L408.2
unnamed: D403.1 (K), R220.1
unnamed: C421.1, D404.1 (K), T451.4
unnamed: D405.2 (A), L406.2
unnamed: C419.1, C420.1, C429.1, D408.1 (K), J401.1, Q402.2 (C), R426.1, T451.7
unnamed: C201.2, J1.1 (In), R129.1
unnamed: C415.1, J2.1 (Pin_1_1), R419.1, R421.2, T451., T451.5
unnamed: C307.2, C310.1, J401.2, R319.2, R353.2
unnamed: C306.2, C307.1, C311.1, J401.3, Q302.1 (E), R314.1, R317.2, R319.1
unnamed: J401.4, L405.2
unnamed: L403.1, T451.9 (HEATER)
unnamed: L406.1, T451.2
unnamed: L407.1, R413.1, R416.1
unnamed: L408.1, R401.1
unnamed: Q201.2 (C), R223.2
unnamed: Q201.1 (E), R222.1, SW201.3
unnamed: DL201.3, Q202.3 (B), R208.1
unnamed: C205.1, Q202.1 (E), R224.1
unnamed: C312.2, Q301.3 (B), R310.2
unnamed: Q303.3 (B), R324.1, R325.1
unnamed: Q303.2 (C), R326.1
unnamed: Q304.3 (B), R326.2, R327.2
unnamed: C417.1, Q401.2 (C), R417.2, T401.1
unnamed: L410.1, Q401.1 (E)
unnamed: C429.2, L401.2, Q402.1 (B)
unnamed: L409.1, Q402.3 (E)
unnamed: C510.1, Q501.14 (0^{O}_IN), R518.1
unnamed: Q501.15 (45^{O}_IN), R518.2, X501.2
unnamed: C503.2, Q501.6 (ACC_FILTER), R503.1
unnamed: C404.1, C405.2, Q501.35 (AFC_OUT), R407.1
unnamed: C513.1, C514.1, Q501.16 (APC_FILTER_1), R521.1, R522.1
unnamed: C515.1, Q501.18 (APC_FILTER_2), R520.2, R521.2, R523.1, TP43.1 (1_1)
unnamed: Q501.22 (B-Y_OUT), R529.1, R530.1
unnamed: C507.1, Q501.10 (BURST_CLEANING)
unnamed: C505.2, Q501.8 (CHROMA_OUT), R511.1, TP42.1 (1_1)
unnamed: C205.2, Q501.3 (CLAMP_IN), R209.1
unnamed: DL201.1, Q501.42 (CONTRAST_OUT_(C)), R207.2
unnamed: Q501.19 (DELAY_IN_/_SYSTEM_SW), R524.1
unnamed: C505.1, Q501.17 (DIRECT_IN)
unnamed: Q501.1 (EMITTER_PEAKING), R205.1, R206.1
unnamed: Q501.20 (G-Y_OUT_/_UNI_COLOR_SW), R525.1, R526.1
unnamed: C413.1, C434.2, L407.2, Q501.32 (H_DRIVE_OUT)
unnamed: C407.2, Q501.34 (H_OSC_TIMING), R409.1, R410.2, R412.2
unnamed: Q501.38 (H_PULSE_IN_GATE_PULSE_OUT), R404.1, R405.1
unnamed: C508.1, Q501.12 (KILLER/IDENT_FILTER), R531.1
unnamed: Q501.21 (R-Y_OUT), R527.1, R528.1
unnamed: C305.1, Q501.27 (RAMP_CAP.), R300.1
unnamed: C401.1, C403.1, Q501.37 (SYNC_SEP._IN), R402.2, R403.1, TP33.1 (1_1)
unnamed: L301.2, Q501.36 (SYNC_SEP._OUT), R304.2
unnamed: C303.2, Q501.28 (V_TRIG.), R303.2
unnamed: Q501.13 (XTAL_DRIVE), R516.1, TP44.1 (1_1)
unnamed: R210.2, R254.1
unnamed: R213.1, R254.3
unnamed: R214.2, R254.2
unnamed: R215.1, R218.2, R255.1
unnamed: R215.2, R229.1, R255.3
unnamed: R229.2, R257.1, R257.2
unnamed: R230.1, R257.3
unnamed: R306.1, R351.2, R351.3
unnamed: R308.2, R352.1, R352.2
unnamed: R315.1, R316.1, R317.1
unnamed: R321.2, R353.3
unnamed: R323.1, R353.1
unnamed: R352.3, R354.1, R355.1
unnamed: R504.2, R508.2, R519.1, R555.1, R555.2
unnamed: R507.1, R555.3
unnamed: R509.2, R554.2
unnamed: R512.2, R554.1
unnamed: R515.1, R554.3
unnamed: R211.1, R212.2, U1.5 (ADJ)

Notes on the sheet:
BOARD MOUNTING HOLES
R300 = BOARD MOD
MOUNTING HOLES FOR FLYBACK SHIELD
10.6V
4.8V
PICTURE CONTROL BOARD CONNECTORS
8.6V
NORMAL SERVICE
- ALL RESISTORS = 1/8 W 5% OR AS MARKED - ALL NON-POLARIZED CAPACITORS = CERAMIC 50 V 5% OR AS MARKED - ALL POLARIZED CAPACITORS = ALUMINUM ELECTROLYTIC OR AS MARKED - ALL MYLAR CAPACITORS = 50 V 5% OR AS MARKED

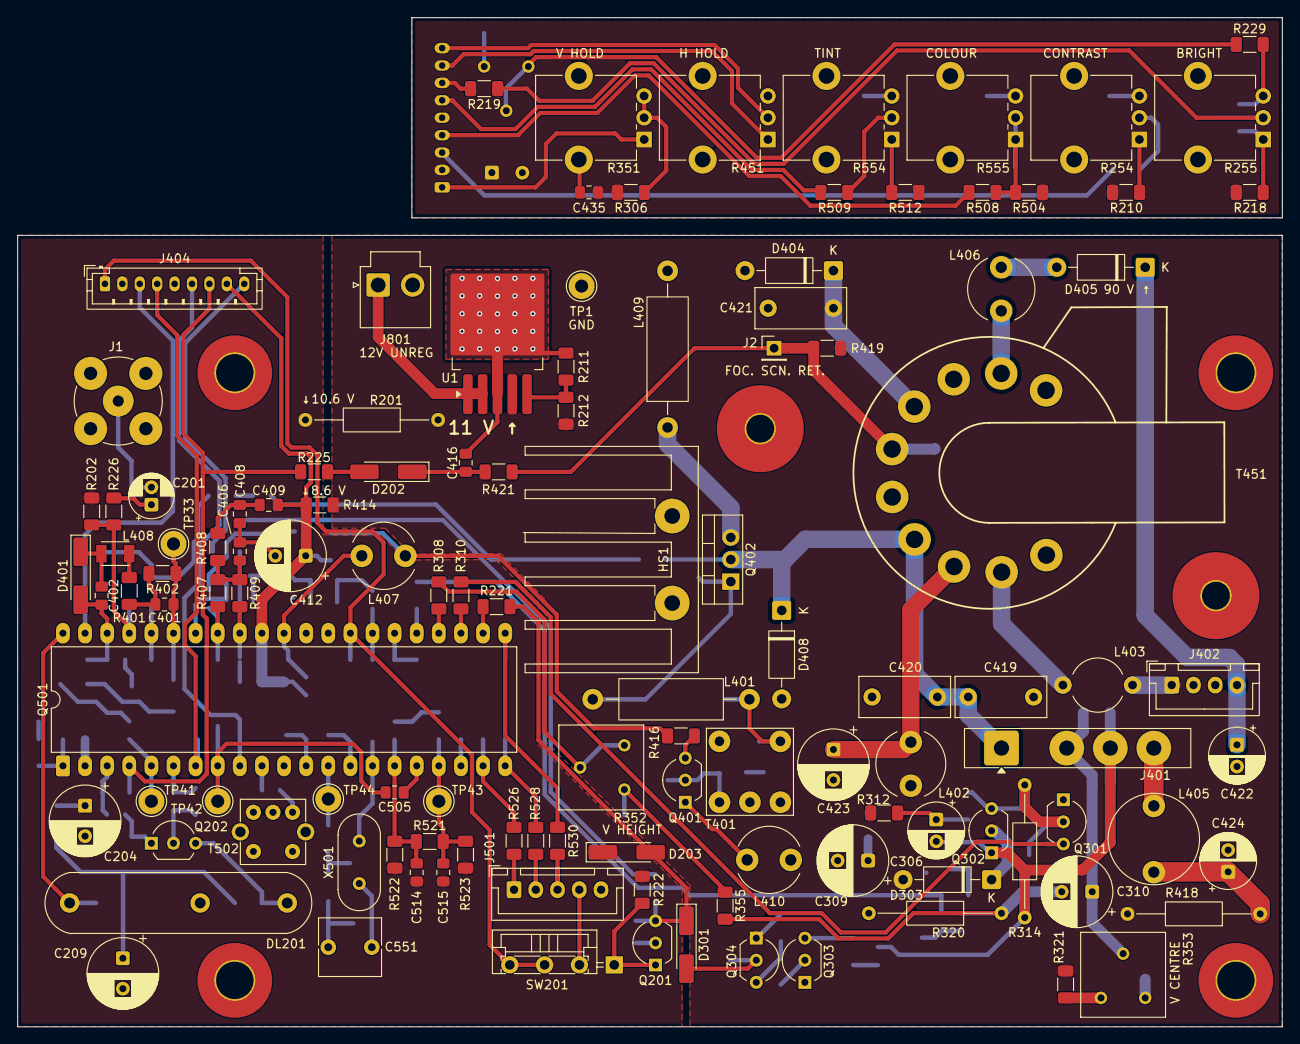
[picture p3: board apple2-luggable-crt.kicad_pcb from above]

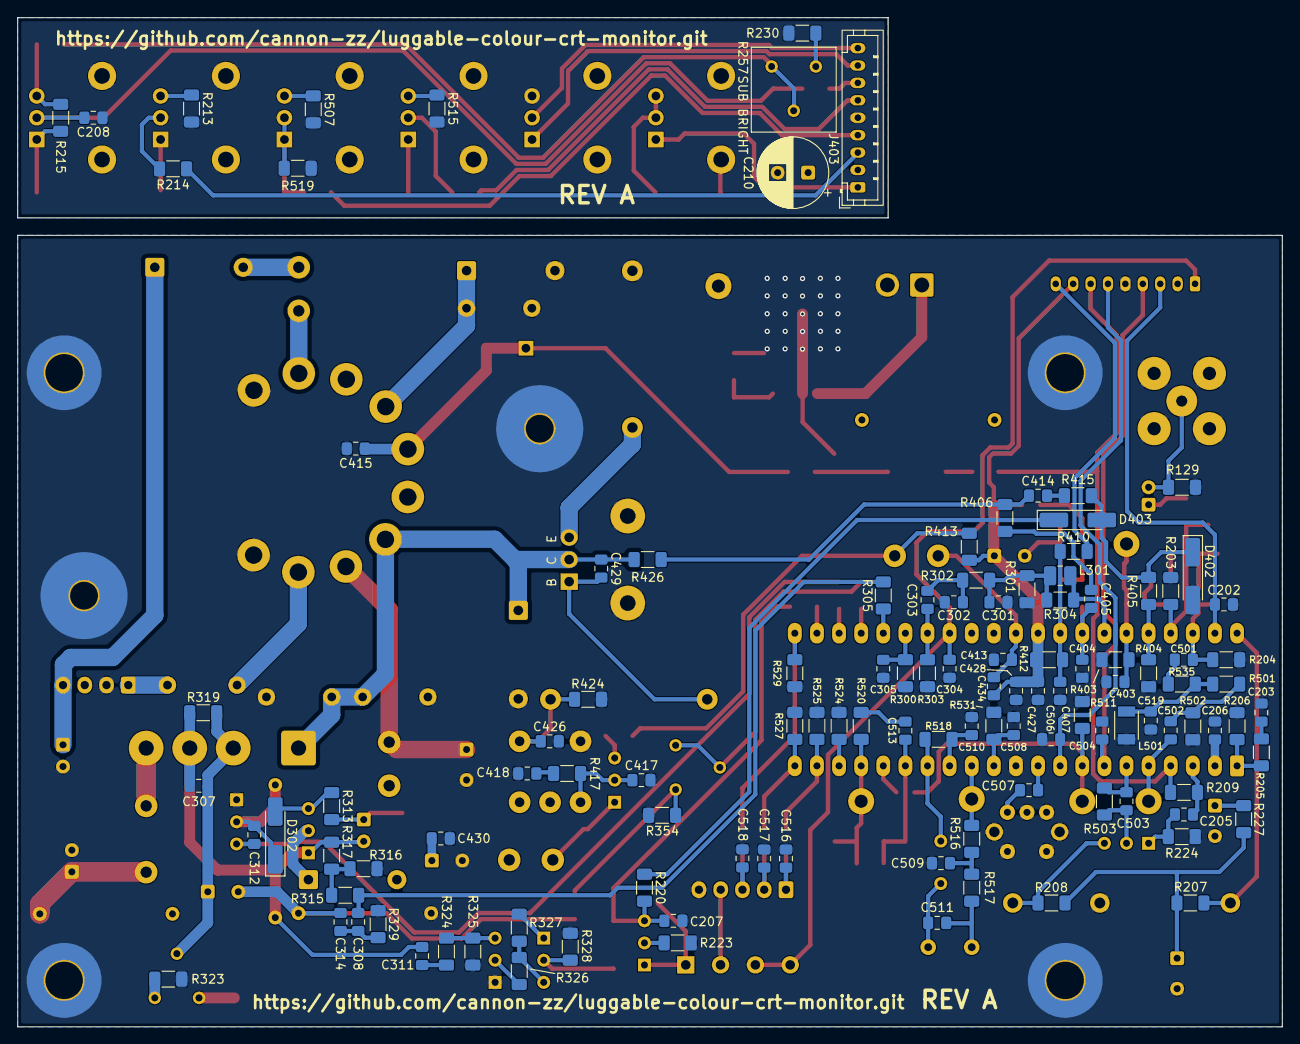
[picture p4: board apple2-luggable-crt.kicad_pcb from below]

Board: 2 copper layers, 145.3 x 115.9 mm, 242 parts (117 on the bottom side), 132 nets.

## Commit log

2026-02-18 reorganize filesystem
    [apple2-luggable-crt.kicad_pcb, apple2-luggable-crt.kicad_sch]
2026-02-19 add pin 10 to the flyback
    [apple2-luggable-crt.kicad_sch]
2026-02-19 correct voltage of external power brick
2026-02-19 work on flyback internal structure
    - move pins around based on resistance measurements.
    [apple2-luggable-crt.kicad_sch]
2026-02-21 compress the schematic layout somewhat
    - page size is currently A4. I think I can get it down to A3 if I squeeze things around. we'll see.
    [apple2-luggable-crt.kicad_sch]
2026-02-22 start assigning footprints
    [apple2-luggable-crt.kicad_sch]
2026-02-22 more work on foot prints
    [apple2-luggable-crt.kicad_sch]
2026-02-23 more progress
    - more foot prints
    - fixed some errors (there was an inductor I had missed altogether)
    - figured out all the inductor values
    - figured out, more or less, most of the diodes
    - rearranged things to squeeze it onto an A3 sheet. when printed onto A4, the components are more compactly arranged but individually larger, and the component values are easier to read.
    [apple2-luggable-crt.kicad_sch]
2026-02-24 more progress
    - fix one of the diodes (turns out not to be a zener)
    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
    [apple2-luggable-crt.kicad_sch]
2026-02-25 more progress
    [apple2-luggable-crt.kicad_sch]
2026-02-26 more progress
    - correct some footprints
2026-02-27 more progress
    - add notes about inductors
    - label the orientations of most variable resistors
    - fix a few other issues here and there
    [apple2-luggable-crt.kicad_sch]
2026-03-01 more progress
    - completed confirming all components out of circuit
    - fixed several errors and omissions
    [apple2-luggable-crt.kicad_sch]
2026-05-05 more work
    [apple2-luggable-crt.kicad_pcb, apple2-luggable-crt.kicad_sch]
2026-07-07 more progress
    - pretty close to being done. now comparing foot prints to parts samples, checking part placement for interference, and making layout adjustments to accommodate PCB mounting holes now that I know where they are.
    [apple2-luggable-crt.kicad_pcb, apple2-luggable-crt.kicad_sch]
2026-07-24 version before heat sink work
    [apple2-luggable-crt.kicad_pcb, apple2-luggable-crt.kicad_sch]
2026-07-24 add REV A to boards
    [apple2-luggable-crt.kicad_pcb]
2026-07-25 some tweaks
    [apple2-luggable-crt.kicad_pcb]
